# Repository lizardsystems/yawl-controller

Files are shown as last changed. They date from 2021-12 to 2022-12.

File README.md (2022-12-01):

# Yet Another WLED Controller

This repository contains a schematic and PCB layout for a yet another WLED controller (yawl-controller).

This is the ESP8266 based wireless pixel controller to drive addressable LED strips like WS2812B/APA102/WS2801/etc using WLED.



## Features



- Compact: 60x35x19mm with case, 59x32x12mm  without case.
- Supports 3-wire and 4-wire LED strips.
- Fuse for overcurrent protection.
- Reverse polarity protection.
- Modern [SN74LVC2T45](https://www.ti.com/product/SN74LVC2T45) bus transceiver with voltage translation. [Why?](level-shifter.md)
- Capacitor 1000 µF at 6.3V, smooths the voltage and sudden changes in demand for current from the LEDs.
- IR receiver (optional).
- Button (optional).
- Dallas temperature sensor for measuring ambient temperature inside of enclosure (optional).
- Connection to relay for reducing power consumption when seemingly switched off (optional).

## Some credits

Thanks to [Christian Schwinne aka Aircoookie](https://github.com/Aircoookie) who created an excelent [WLED Project](https://github.com/Aircoookie/WLED) - a fast and feature-rich implementation of an ESP8266/ESP32 webserver to control NeoPixel (WS2812B, WS2811, SK6812) LEDs or also SPI based chipsets like the WS2801 and APA102.

Schematics are based on manufacturers datasheets but some component values come from [Adafruit Learning System](https://learn.adafruit.com/) so thanks to Adafruit for keeping their products open source.

## The Idea

Small and simple device for 5V addressable LED strips with minimum components and fully assembled by PCB manufacturing service in standard case.

## Schematic

This is the schematic of YAWL controller

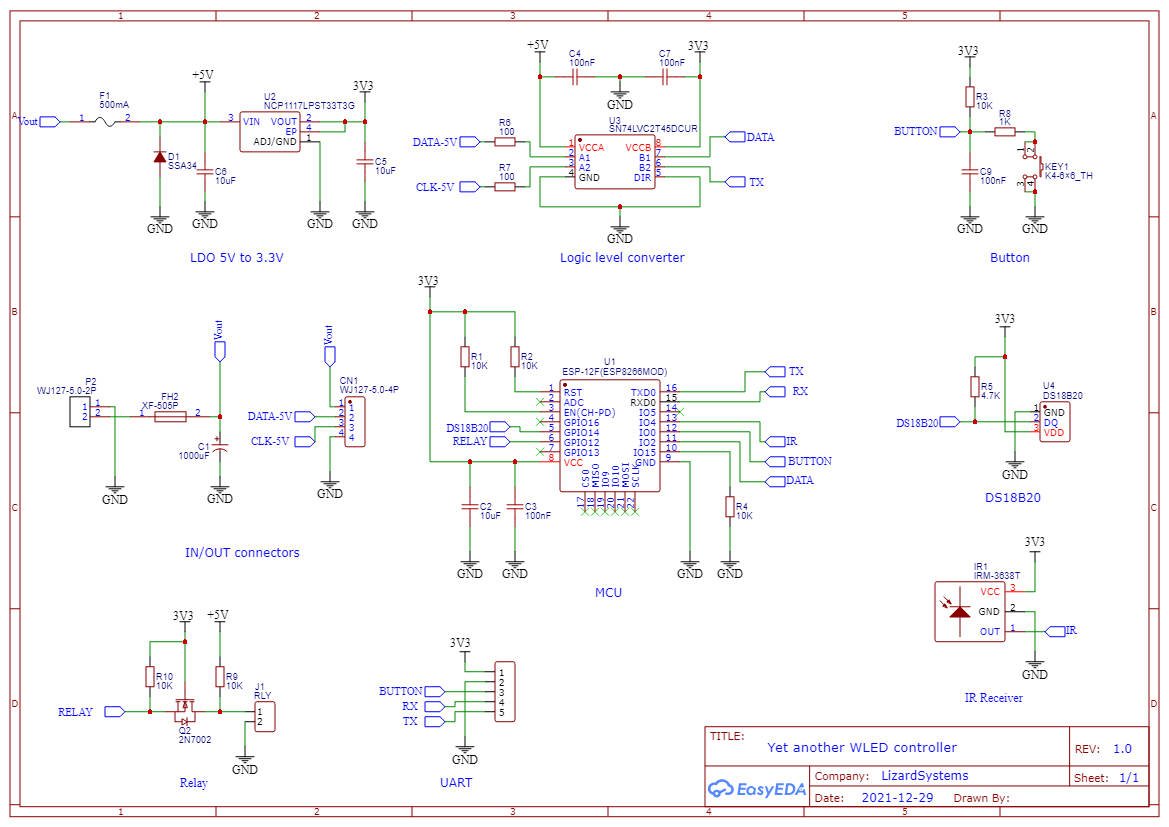
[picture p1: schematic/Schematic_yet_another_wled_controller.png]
Schematic


Download pdf file [Schematic_yet_another_wled_controller.pdf](Schematic_yet_another_wled_controller..pdf)

## GPIO Pinout

| Pin | Function |
| --- | ---|
| GPIO0 | Push Button |
|  GPIO1 | LED CLK |
|  GPIO2 | LED DATA |
|  GPIO4 | IR Receiver |
| GPIO12 | Relay |
| GPIO14 | Temperature Sensor |

## PCB

Dimensions:

- Width x Height: 59x32mm
- Thickness: 1.6mm

### 2D View

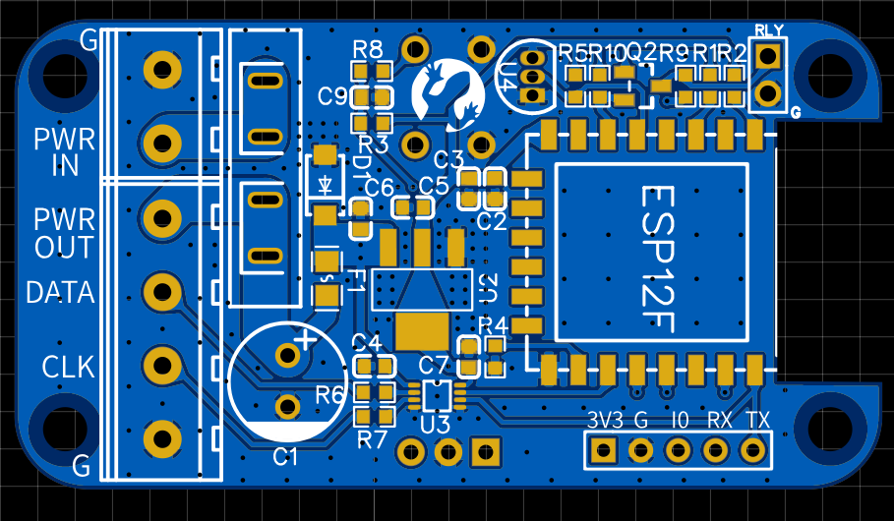
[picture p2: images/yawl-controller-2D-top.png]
2D View


### 3D View

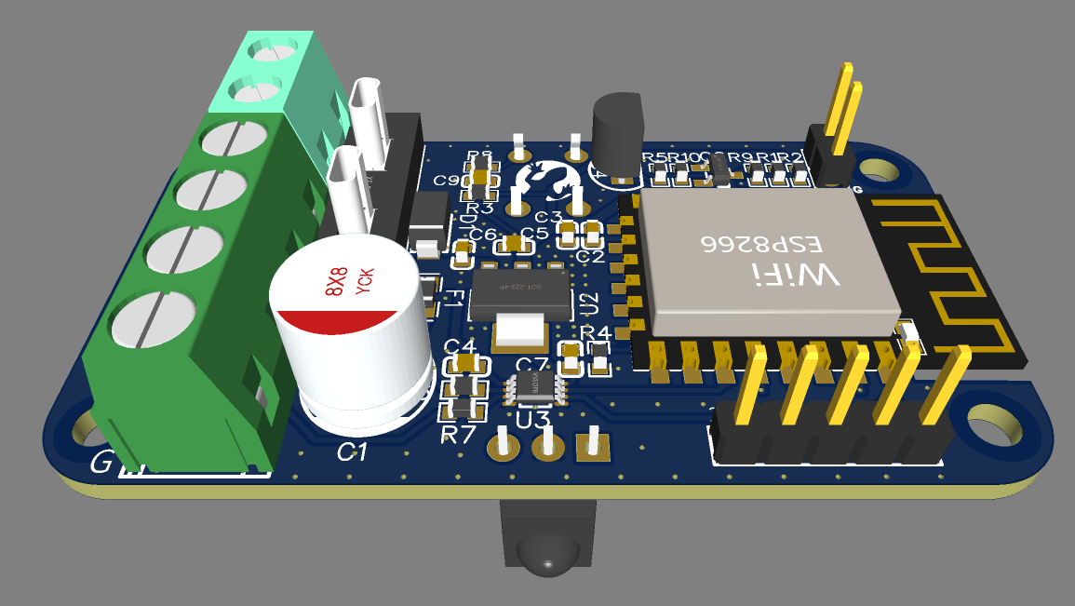
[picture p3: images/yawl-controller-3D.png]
3D View


## Enclosure

Read more about the YAWL controller [enclosures](/enclosures/README.md).

## Ordering and manufacturing

- Gerber files: [Gerber_PCB_yet_another_wled_controller.zip](fabrication/Gerber_PCB_yet_another_wled_controller.zip)
- BOM file: [BOM_PCB_yet_another_wled_controller.csv](fabrication/BOM_PCB_yet_another_wled_controller.csv)
- BOM file (JLCPCB): [BOM_PCB_yet_another_wled_controller_(JLCPCB).xls](fabrication/BOM_PCB_yet_another_wled_controller_(JLCPCB).xls)
- CPL file: [PickAndPlace_PCB_yet_another_wled_controller.csv](fabrication/PickAndPlace_PCB_yet_another_wled_controller.csv)

## Hardware

### PCB manufactured by JLCPCB



### SMT assembled PCB



### Manual soldering and assembling



- Fuse Holder [Micro](https://aliexpress.ru/item/4000541087990.html), Fuse 10A [Micro](https://aliexpress.ru/item/4000568246661.html) 
- IR Receiver (optional) [TSOP38238](https://aliexpress.ru/item/32834341300.html)
- Temperature Sensor (optional) [DS18B20](https://aliexpress.ru/item/32523899337.html)
- 3x Screw Terminal 5mm (optional) [2P](https://aliexpress.ru/item/4000084631795.html)
- Relay Screw Terminal 2.54mm (optional) [2P](https://aliexpress.ru/item/4000867583795.html)
- Push Button (optional) [6x6x9mm](https://aliexpress.ru/item/32912104842.html)
- DC Power Pigtail Female Plug [5.5x2.1mm](https://www.aliexpress.com/af/pigtail-dc-female-5.5x2.1mm.html)
- JST SM Connector [3pin](https://www.aliexpress.com/item/1718558728.html)
- Enclosure (optional) [80x38x22mm-Black](https://aliexpress.ru/item/1005002656761229.html) or [style 2](https://aliexpress.ru/item/1005001677364663.html)

### Assembled device



With all optional parts



### With enclosure



## Ready to use firmware

- [Custom WLED Firmware](firmware/WLED/)
- [Custom ESPHome Firmware](firmware/ESPHome)

## Resources

- [WLED](https://github.com/Aircoookie/WLED) 
- [ESPHOME](https://esphome.io/)

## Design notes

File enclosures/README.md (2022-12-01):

# Enclosures

## Ready-to-use enclosures

PCB is designed for SZOMK [AK-S-80](/datasheets/AK-S-80.pdf) case

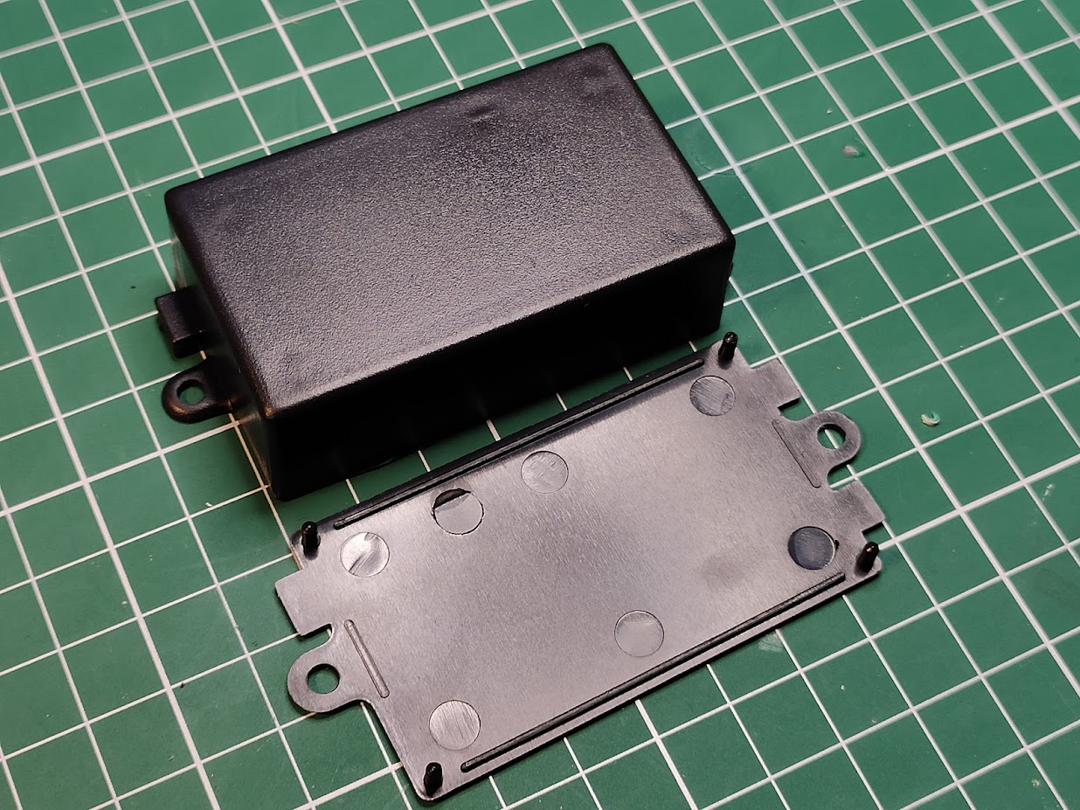
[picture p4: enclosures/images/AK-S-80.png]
AK-S-80


Buy on Aliexpress: [80x38x22mm-Black](https://aliexpress.ru/item/1005002656761229.html) or [style 2](https://aliexpress.ru/item/1005001677364663.html)

## 3D printed enclosures

Two enclosures designed by [@chunkysteveo](https://github.com/chunkysteveo) based on [Customizable everything box (waterproof) by mcseven](https://www.thingiverse.com/thing:1680291/files)

The screw holes are 3.4mm diameter, that allows to get an M3 screw through the lid, and melt an M3 threaded insert into the body.

### With external antenna

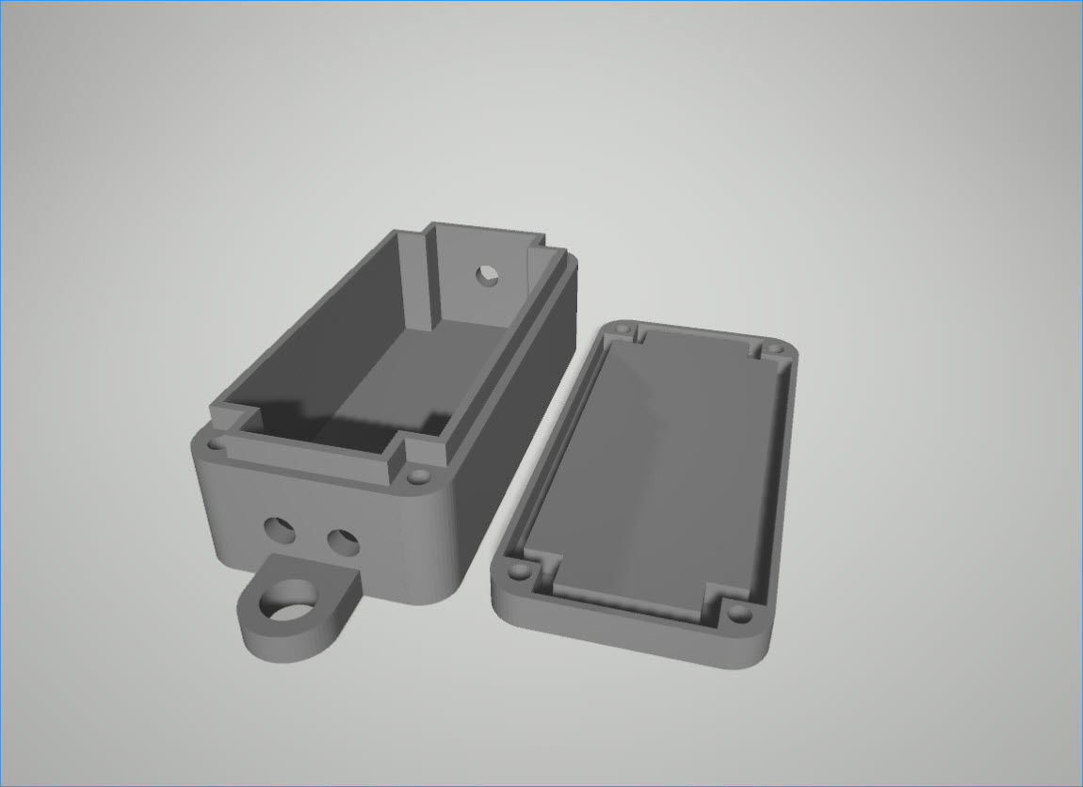
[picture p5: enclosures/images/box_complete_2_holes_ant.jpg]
box_complete_2_holes_ant


Download STL file: [box_complete_2_holes_ant.zip](/enclosures/box_complete_2_holes_ant.zip)

### Without external antenna  

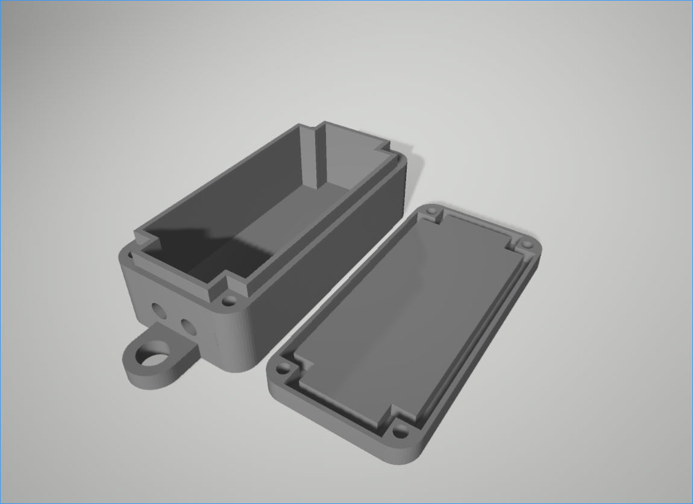
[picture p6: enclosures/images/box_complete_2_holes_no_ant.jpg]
box_complete_2_holes_no_ant


Download STL file: [box_complete_2_holes_no_ant.zip](/enclosures/box_complete_2_holes_no_ant.zip)

### YAWL controller in 3D printed enclosure

3d-printed-enclosure

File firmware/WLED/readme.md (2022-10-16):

wled_logo_akemi

# WLED

## Download ready-to-use firmware

### YAWL firmware
You may download a ready-to-use firmware [yawl_controller.bin ](firmware/WLED/bin/yawl_controller.bin).

### Standard firmware

You can get further information on the various WLED firmware versions https://kno.wled.ge/basics/install-binary/

## Build custom firmware

Also you may compile the firmware by self using Visual Studio Code and Platformio. 
 - Download and install Git client: https://git-scm.com/downloads.
 - Download and install Visual Studio Code: https://code.visualstudio.com/download.
 - Install PlatformIO extension in Visual Studio Code: https://docs.platformio.org/en/latest//integration/ide/vscode.html#installation
 - Download WLED Github Master ZIP: https://github.com/Aircoookie/WLED/archive/refs/heads/master.zip
 - Unpack in directory somewhere
 - "Open folder" in Visual Studio Code
 - Build project with <kbd>Ctrl</kbd>+<kbd>Alt</kbd>+<kbd>B</kbd> hotkey
 - Build standard WLED.
 - If the file is created successfully then you can proceed to the next step, if not please read [this article](https://kno.wled.ge/basics/compiling-wled/) for more information.  
 - Copy [platformio_override.ini](platformio_override.ini) to WLED folder 
 - Build custom WLED firmware.
 - Please find built firmwae in WLED/build_output/firmware folder



If you still have questions for more information please read a step-by-step guide at [this page](https://kno.wled.ge/basics/compiling-wled/) of the WLED Wiki    

## Build the firmware from command line

 - Edit file **env.cmd** from yawl-controller/firmware/ESPHome/ directory. 
   - Set `PYTHON_PATH` to Python installed on your system.
   - Set `PLATFORMIO_VENV` to path to virtual environment where Platformio will be installed.
   - Set `PLATFORMIO_REPO` to url for Platformio repository. Default: https://github.com/platformio/platformio-core
   - Set `PLATFORMIO_BRANCH` to branch name or tag in Platformio repository. Default: master
   - Set `WLED_REPO` to url for WLED repository. Default: https://github.com/Aircoookie/WLED
   - Set `WLED_BRANCH` to branch name or tag in WLED repository. Default: master
 - Run **install_platformio.cmd**. The latest version of Platformio will be installed.
 - Run **compile.cmd**. The firmware will be compiled and copied to yawl-controller/firmware/WLED/ directory. File **yawl_controller_WLED_`{WLED_VERSION}`.bin** will be created, where `{WLED_VERSION}` - version of WLED.  

## Connect controller to computer

| YAWL Controller |	USB to Serial Adapter|
|---|---|
| 3.3v	| 3.3v |
| Ground	| Ground |
| IO0	| Ground |
| TX	| RX |
| RX	| TX |



## Flash firmware
Download flasher https://github.com/esphome/esphome-flasher/releases
Open the flasher tool.
 - Serial port: select COM port where the controller is connected (there is probably only one option).
 - Firmware: Browse to the location where you downloaded your compiled firmware and select your firmware.



- Click Flash ESP and wait.

The controller will be flashed now, you can follow the progress in the console window.
When finished writing the firmware, switch off controller.

## Hardware Setup

### GPIO Pinout
| Pin | Function | 
| --- | ---|
| GPIO0 | Push Button | 
|  GPIO1 | LED CLK |
|  GPIO2 | LED DATA |
|  GPIO4 | IR Receiver |
| GPIO12 | Relay | 
| GPIO14 | Temperature Sensor |

### 3-Wire LED Strip 


1. Select 3-wire LED Strip like a WS281x
2. Data GPIO: 2 

### 4-Wire LED Strip


1. Select 4-wire LED Strip like a APA102
2. GPIOs: 
   - Data GPIO: 2
   - Clk GPIO: 1

### Temperature


YAWL Controller uses GPIO 14 for temperature sensor DS18B20 (DALLAS)



### IR receiver


YAWL controller uses GPIO 4 for IR receiver. 

Information about infrared receivers https://kno.wled.ge/interfaces/infrared/

### Relay


YAWL controller uses GPIO 12 for controlling relay. 

Installing relay https://kno.wled.ge/features/relay-control/

### Button


YAWL controller uses GPIO 0 for button. 

## Multi-strip Support

You are able to use multiple LED outputs from one yawl-controller. Pins and LED numbers can be easily configured in LED settings, you don't need to re-compile code for your specific setup. You may use use two specific LED pins, GPIO1 (CLK) and GPIO2 (DATA) for two 3-wires strips 

### GPIO Pinout
| Pin | Function | 
| --- | ---|
|  GPIO1 | LED DATA #1 |
|  GPIO2 | LED DATA #2 |

### Wiring



### WLED Config



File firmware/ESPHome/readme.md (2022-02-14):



# ESPHome

## FastLED or NeoPixelBus
You may create your own firmaware using ESPHome and FastLED or NeoPixelBus library or download ready to use firmware.

For more information about FastLED library:
- ESPHome FastLED Light Platform https://esphome.io/components/light/fastled.html
- FastLED repository https://github.com/FastLED/FastLED
- ESPHome NeoPixelBus Light Platform https://esphome.io/components/light/neopixelbus.html
- NeoPixelBus repository https://github.com/Makuna/NeoPixelBus

### Download ready to use firmware

Download firmware [yawl-controller-fastled.bin](yawl-controller-fastled.bin) or  [yawl-controller-neopixelbus.bin](yawl-controller-neopixelbus.bin) from this repository for 3-wire LED strip (NeoPixels, one data wire). If you want to use 4-wire LED strip (DotStars, two wire, one data and one clock) please read below. 

### Build the firmware itself

#### 3-Wire LED Strip

NeoPixels, one data wire:
- WS2811, WS2812, WS2812b, WS2813
- APA106
- SK6812
- LC8812
- TM1814,TM1914,TM1829

Download YAML configuration file [yawl-controller-neopixelbus.yaml](yawl-controller-neopixelbus.yaml) or [yawl-controller-fastled.yaml](yawl-controller-fastled.yaml) from this repository and compile using ESPHome.

#### 4-Wire LED Strip

DotStars, two wire, one data and one clock
- APA102
- SK9822
- LPD6803, LPD8806
- WS2801
- P9813

##### FastLED

Please change light options in yawl-controller-fastled.yaml

```yml
light:
  - platform: fastled_spi
    id: light_1
    rgb_order: GRB
    chipset: APA102
    data_pin: GPIO2
    clock_pin: GPIO1
```
#### NeoPixelBus

**Unfortunately NeoPixelBus does not support GPIO2 and GPIO1 for 4-wire LED strip. On ESP8266 NeoPixelBus supports only GPIO13 for data_pin and only GPIO14 for clock_pin.** 

Please read [Getting Started with ESPHome](https://esphome.io/guides/getting_started_command_line.html) and [Getting Started with ESPHome and Home Assistant](https://esphome.io/guides/getting_started_hassio.html)

### Build the firmware from command line

If you want to flash firmware from command line you may skip this section and go to "**Flash using command line**"

 1) Edit file **env.cmd** from yawl-controller/firmware/ESPHome/ directory. 
   - Set `PYTHON_PATH` to Python installed on your system.
   - Set `ESPHOME_VENV` to path to virtual environment where ESPHome will be installed.
   - Set `ESPHOME_REPO` to url for ESPHome repository. Default: https://github.com/esphome/esphome
   - Set `ESPHOME_BRANCH` to branch name or tag in ESPHome repository. Default: release
 2) Run **install_esphome.cmd**. The latest version of ESPHome will be installed.
 3) Run **compile_fastled.cmd** or **compile_neopixelbus.cmd**. The firmware will be compiled and copied to yawl-controller/firmware/ESPHome/ directory. yawl-controller-fastled.bin or yawl-controller-neopixelbus.bin will be updated.  

## Connect controller to computer

| YAWL Controller |	USB to Serial Adapter|
|---|---|
| 3.3v	| 3.3v |
| Ground	| Ground |
| IO0	| Ground |
| TX	| RX |
| RX	| TX |



## Flash firmware

### Flash using ESPHome Flasher

- Download flasher https://github.com/esphome/esphome-flasher/releases
 - Open the flasher tool.
   - Serial port: select COM port where the controller is connected (there is probably only one option).
   - Firmware: Browse to the location where you downloaded your compiled firmware and select your firmware.
   - Click Flash ESP and wait.

esphome_flash

The controller will be flashed now, you can follow the progress in the console window.
When finished writing the firmware, switch off controller.

### Flash using command line

1) Edit file **env.cmd** from yawl-controller/firmware/ESPHome/ directory. 
   - Set `PYTHON_PATH` to Python installed on your system.
   - Set `ESPHOME_VENV` to path to virtual environment where ESPHome will be installed.
   - Set `ESPHOME_REPO` to url for ESPHome repository. Default: https://github.com/esphome/esphome
   - Set `ESPHOME_BRANCH` to branch name or tag in ESPHome repository. Default: release
2) Run **install_esphome.cmd**. The latest version of ESPHome will be installed.

Once done, you can then go ahead and run the following command **flash_fastled.cmd** or **flash_neopixelbus.cmd** which will instruct ESPHome to flash YAWL controller firmware. This will take a minute or two to complete, at which point you will then be asked how you want to upload. Select the option for serial and it should begin to upload.

yawl_flash

Assuming everything was successful, you can now disconnect everything from the USB adaptor.

## Connect controller to Wi-Fi network

When you are using ready-to-use firmware, at the first start, the controller will create its own network "yawl-controller-XXXXXX". 

When you are connecting to the fallback network, the web interface should open automatically (see also login to network notifications). If it doesn't open, you may also navigate to http://192.168.4.1/ manually in your browser.



In this web interface, you may manually override the WiFi settings.

Additionally, you may upload a new firmware file.

## See also
 - https://esphome.io/guides/getting_started_hassio.html

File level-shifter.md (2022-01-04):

# Level shifter

yawl-controller uses SN74LVC2T45 as level shifter - 2-Bit Dual Supply Transceiver with Configurable Voltage-Level Shifting and 3-State Outputs. 

[SN74LVC2T45 Datasheet](datasheets/1809042112_Texas-Instruments-SN74LVC2T45DCUR_C15741.pdf)

## Speed

SN74LVC2T45 2x faster than SN74AHCT125N and 4x faster than SN74HCT125N



## Size

SN74LVC2T45 8x smaller than SN74AHCT125N

- SN74AHCT125N (PDIP-14) 19.05x6.35x3.3mm 
- SN74LVC2T45DCUR  (VSSOP-8) - 2x2.3x1mm



## Price

 - SN74AHCT125N - [US$ 0.29](https://lcsc.com/product-detail/Buffers-Drivers_Texas-Instruments-SN74AHCT125N_C354152.html)
 - SN74LVC2T45DCUR - [US$ 0.44](https://lcsc.com/product-detail/Receivers-Transceivers_Texas-Instruments-SN74LVC2T45DCUR_C15741.html)

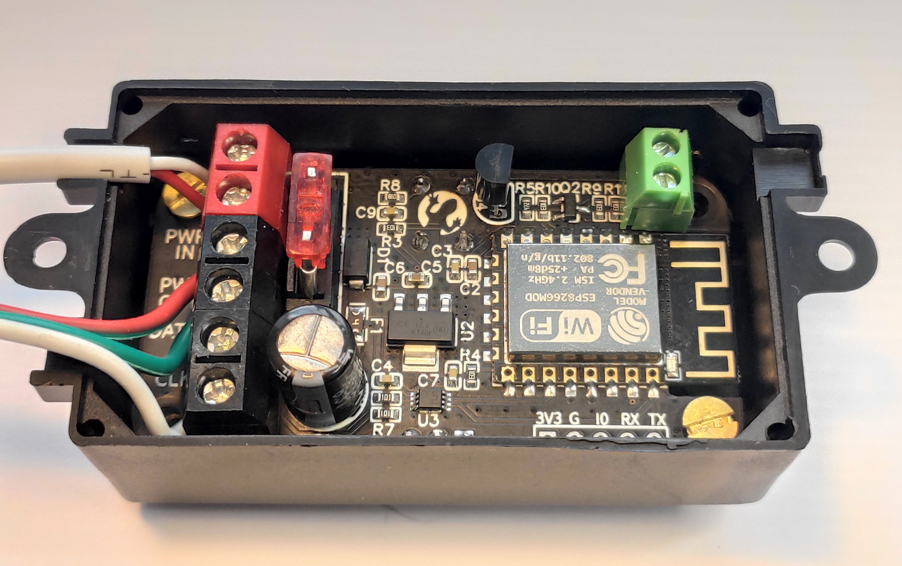
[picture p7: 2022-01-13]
images/yawl-controller-with-case.jpg

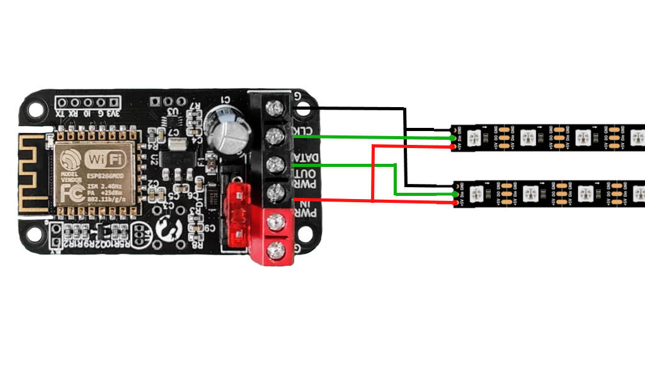
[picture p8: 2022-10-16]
images/yawl-controller-multi-strip-support.jpg

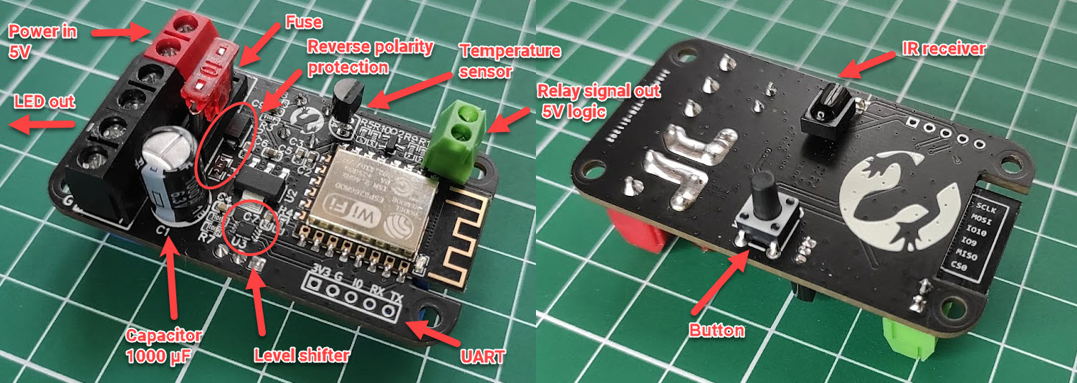
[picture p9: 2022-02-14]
images/yawl-controller-features.jpg

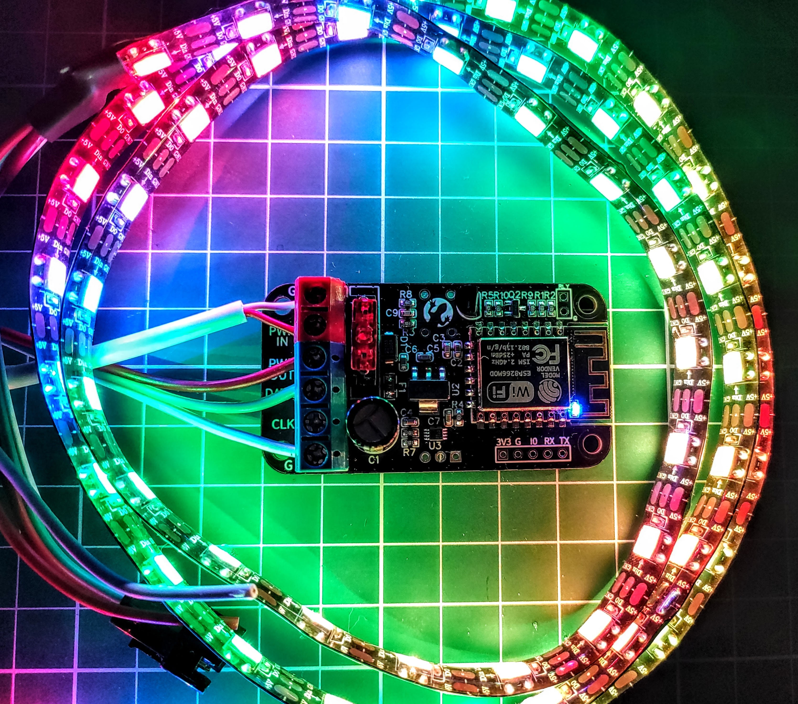
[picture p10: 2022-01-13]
images/yawl-controller.jpg

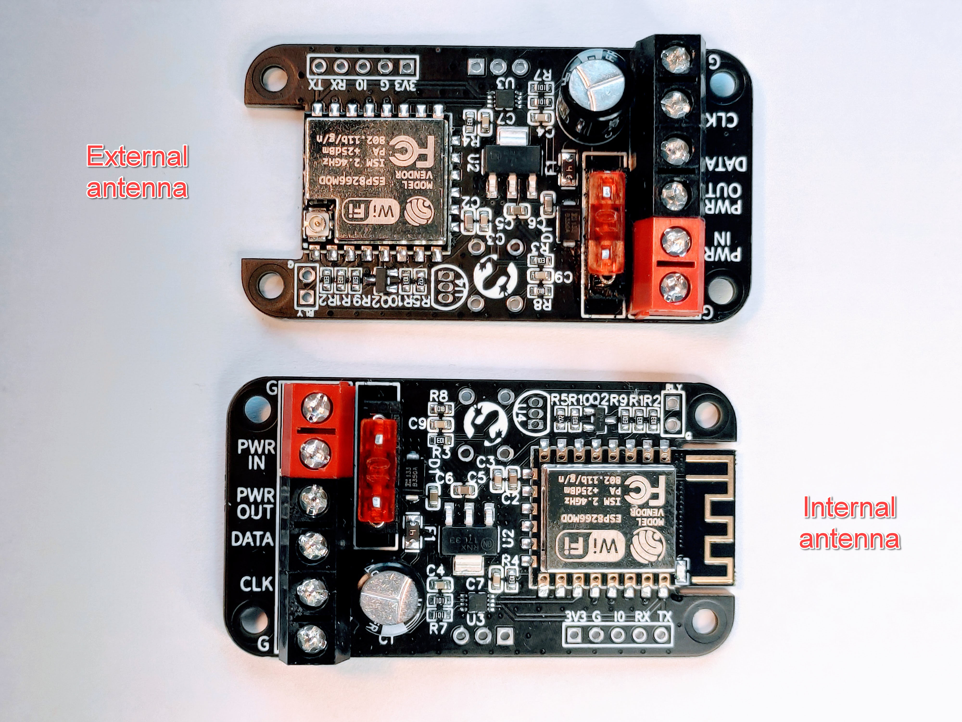
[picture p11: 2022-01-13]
images/yawl-controller-antenna-variations.jpg

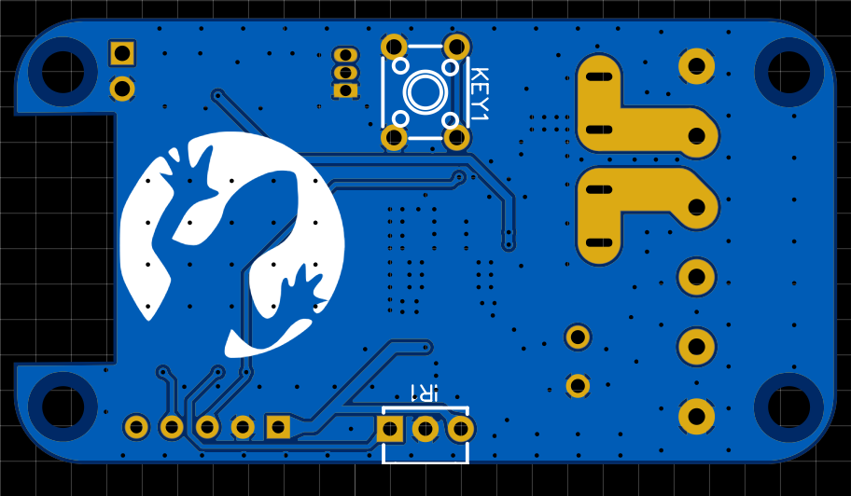
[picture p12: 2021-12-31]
images/yawl-controller-2D-bottom.png

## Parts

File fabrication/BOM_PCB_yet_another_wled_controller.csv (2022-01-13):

ID | Name | Designator | Footprint | Quantity | Manufacturer Part | Manufacturer | Supplier | Supplier Part | Price
1 | 1000uF | C1 | CAP-TH_BD8.0-P3.50-D0.6-FD | 1 | 1000uF 10V 8*12 | ValuePro | LCSC | C10752 | 0.03
2 | 10uF | C2,C5,C6 | C0603 | 3 | CL10A106KP8NNNC | SAMSUNG | LCSC | C19702 | 0.006
3 | 100nF | C3,C4,C7,C9 | C0603 | 4 | CC0603KRX7R9BB104 | YAGEO | LCSC | C14663 | 0.002
4 | WJ127-5.0-4P | CN1 | CONN-TH_4P-P5.00_WJ127-5.0-4P | 1 | WJ127-5.0-4P | Ningbo Kangnex Elec | LCSC | C192779 | 0.193
5 | SS34 | D1 | DO-214AC_L4.3-W2.7-LS5.3-RD | 1 | SS34 | MDD | LCSC | C8678 | 0.04
6 | 500mA | F1 | F0805 | 1 | MF-PSMF050X-2 | BOURNS | LCSC | C116170 | 0.025
7 | XF-505P | FH2 | FUSE-TH_XF-505P | 1 | XF-505P | XFCN | LCSC | C843270 | 0.15
8 | IRM-3638T | IR1 | OPTO-TH_IRM-3638T | 1 | IRM-3638T | EVERLIGHT | LCSC | C16216 | 0.217
9 | K4-6×6_TH | KEY1 | KEY-TH_4P-L6.0-W6.0-P4.50-LS6.5 | 1 | K2-1102DP-E4SW-04 | 韩国韩荣 | LCSC | C136684 | 0.036
10 | WJ127-5.0-2P | P2 | CONN-TH_2P-P5.00_CPC3703CTR | 1 | WJ127-5.0-2P | ReliaPro | LCSC | C3703 | 0.119
11 | 2N7002 | Q2 | SOT-23-3_L2.9-W1.3-P1.90-LS2.4-BR | 1 | 2N7002 | CJ | LCSC | C8545 | 0.021
12 | 10K | R1,R2,R3,R4,R9,R10 | R0603 | 6 | 0603WAF1002T5E | UniOhm | LCSC | C25804 | 0.001
13 | 4.7K | R5 | R0603 | 1 | 0603WAF4701T5E | UniOhm | LCSC | C23162 | 0.001
14 | 100 | R6,R7 | R0603 | 2 | 0603WAF1000T5E | UniOhm | LCSC | C22775 | 0.001
15 | 1K | R8 | R0603 | 1 | 0603WAF1001T5E | UniOhm | LCSC | C21190 | 0.001
16 | ESP-12F(ESP8266MOD) | U1 | WIFIM-SMD_ESP-12F-ESP8266MOD | 1 | ESP-12F(ESP8266MOD) | Ai-Thinker | LCSC | C82891 | 1.48
17 | NCP1117LPST33T3G | U2 | SOT-223_L6.5-W3.5-P2.30-LS7.0-BR | 1 | NCP1117LPST33T3G | ON | LCSC | C146799 | 0.273
18 | SN74LVC2T45DCUR | U3 | VSSOP-8_L2.4-W2.1-P0.50-LS3.2-BR | 1 | SN74LVC2T45DCUR | TI | LCSC | C15741 | 0.387
19 | DS18B20 | U4 | TO-92-3_L4.9-W3.7-P1.27-L | 1 | DS18B20 | Youtai Semiconductor Co., Ltd. | LCSC | C376006 | 0.798

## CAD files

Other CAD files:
datasheets/AK-S-80.dxf
datasheets/AK-S-80.dwg

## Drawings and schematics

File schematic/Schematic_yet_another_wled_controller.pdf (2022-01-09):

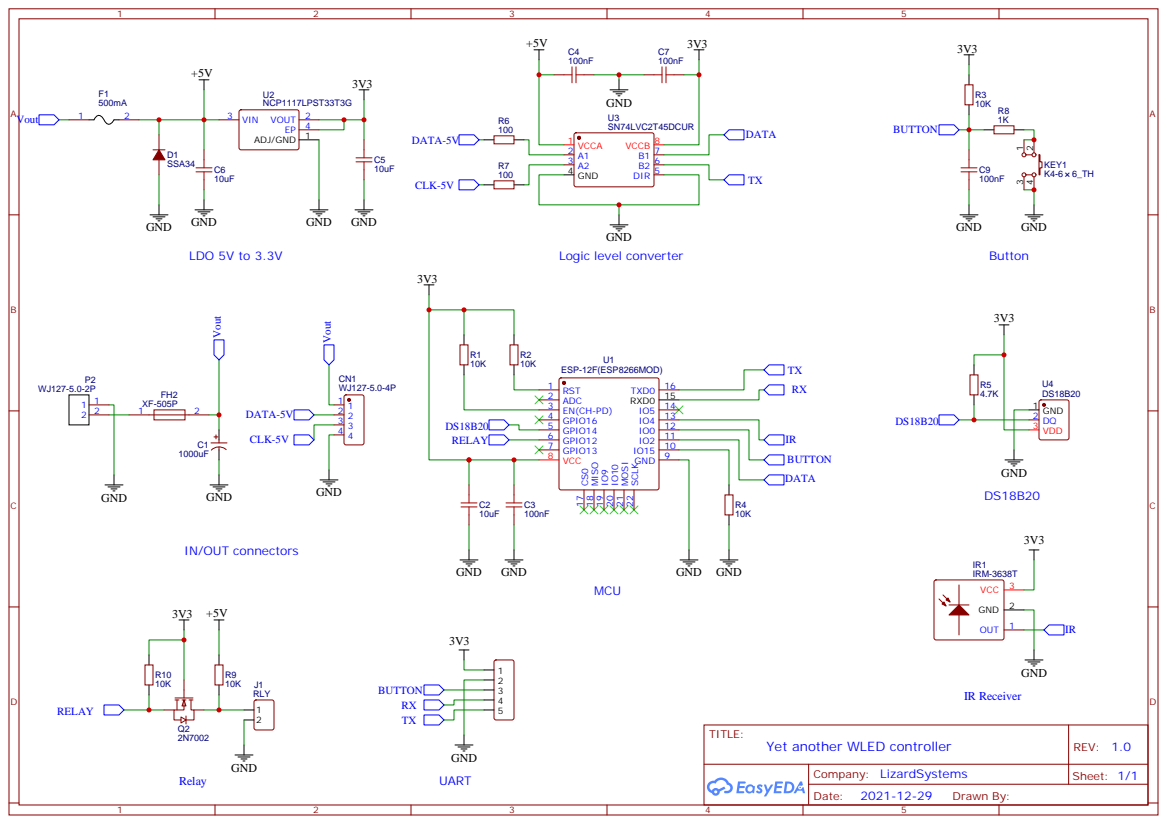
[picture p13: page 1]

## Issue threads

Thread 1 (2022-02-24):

YAWL - Order @ JLCPCB - CPL-File

Masterbandit, 2022-02-24:
Hi,

I am interested in your controller and tried to order it at JLCPCB to create and assemble the pcb.
It is all working fine until the last step. When I add BOM and CPL and press Enter, it takes a long
time and it appears the error "Incorrect format" "Failed processing the CPL file". I tried both BOMs
with the one CPL.

Can you please check this, I really want to try your nice controller.

Sincerely

Masterbandit

vzagorovskiy, 2022-02-24:
Hi,
Do not download file from link

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

 Please download zip file from main page https://github.com/lizardsystems/yawl-controller/

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

Closed 2022-03-03.

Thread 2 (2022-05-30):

maximum Current

moonilightshaker, 2022-05-30:
Hello, what are the maximum current for the Power traces?
Thanks

vzagorovskiy, 2022-05-30:
All Christmas and New Year holidays the controller worked successfully with 200 LEDs on the Christmas tree. The temperature of the board did not exceed 35 degrees Celsius. By all calculations, if you strengthen the tracks as shown in the photo, the controller should work up to 8A-10A. If you need more, it is better to connect as shown in the diagram below.

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

moonilightshaker, 2022-05-30:
Thanks for the Info.

Closed 2022-05-31.

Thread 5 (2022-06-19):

Can this board also work with 12v?

mctigger, 2022-06-19:
Hi,
I am wondering whether this board will work with 12v or needs some small modifications?

vzagorovskiy, 2022-06-20:
You may use use a separate power supply or a dc-dc converter
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

mctigger, 2022-06-20:
Thank you, so an additional buck-converter is needed.

Closed 2022-06-20.

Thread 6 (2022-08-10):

Fuze F1 necessary?

PhillipRt, 2022-08-10:
Is the Fuze F1 (MF-PSMF050X-2) a required part or can I bridge it with solder? The part is out of stock everywhere.

vzagorovskiy, 2022-08-10:
Hello, you may use C20978 or any 6V 500mA  0805 Resettable Fuses

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

vzagorovskiy, 2022-08-10:
It is part of reverse polarity protection circuit. Yes,  you may not use this element, but it may not be safe if you accidentally reverse the power polarity.

chunkysteveo, 2022-09-13:
https://lcsc.com/product-detail/Resettable-Fuses_BOURNS-MF-PSMF050X-2_C116170.html

180 in stock currently at time of posting this @PhillipRt

Closed 2022-11-25.

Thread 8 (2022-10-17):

Ordering instructions for JLCPCB

habeas81, 2022-10-17:
I've never ordered a PCB, though I've considered it many times.  I'd appreciate it greatly if this repo had an ordering guide for what options to choose in terms of the PCB production and assembly.  I'm happy to create it and commit it if you might be willing to help me walk through what I should choose on the website.

Thanks in advance!  Awesome work and super grateful for you creating and sharing this.

vzagorovskiy, 2022-10-17:
https://oshwlab.com/Daisy/How-To-Order-SMT-Service-From-JLCPCB-PCB-Components

Closed 2022-11-25.

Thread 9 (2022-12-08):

Version with swappable esp8266/32

Dunky13, 2022-12-08:
Have a pcb versions with headers I stead of the soldered esp12f.
Either a D1 edition, or a "full size" nodemcu version?

So the pcb is bare board, and a controller can be plugged in.

Useful for people who don't have, or don't want to use an ftdi programming board, or worry about connecting ground to g(nd) and io.

vzagorovskiy, 2022-12-08:
You may use [quinled controllers](https://quinled.info/pre-assembled-quinled-dig-uno/) or shields from serg74[tindie](https://www.tindie.com/products/serg74/wled-mini-shield-board-for-addressable-leds/)

chunkysteveo, 2023-04-26:
Something I'm working on @Dunky13  [TTGO T-Micro32 board](https://github.com/lizardsystems/yawl-controller/issues/13)

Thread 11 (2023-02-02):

Board Source?

aaron-harvey, 2023-02-02:
Hello, I'd like to add esp32 support, is it possible to get the source file to make modifications?

chunkysteveo, 2023-04-26:
Something I'm working on @aaron-harvey [TTGO T-Micro32 board](https://github.com/lizardsystems/yawl-controller/issues/13)

vzagorovskiy, 2023-04-26:
[yawl-controller.zip](https://github.com/lizardsystems/yawl-controller/files/11333740/yawl-controller.zip)

EasyEDA files

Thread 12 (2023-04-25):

Possibility of breaking out the ADC for an electret Mic. Reactive lights

TheBestJohn, 2023-04-25:
Looks as if Pin 2 is unused, If it was broken out to a header then we could use it to enable reactive lights with a mic.
Maybe break out all unused pins and add a ground and 3.3v pin for good measure to allow for modifications?

TheBestJohn, 2023-04-25:
Alternative if anyone really wants this is sending UDP frames, it does cut out the WLED side though, you're essentially just turning it into a network RGB strip instead of leaning on the processing. That being said, the ESP8266 processing limitations may just make this not worth the effort for this project.

Closed 2023-04-25.

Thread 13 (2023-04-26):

New adapter for ESP32 (TTGO T-Micro32)

chunkysteveo, 2023-04-26:
I'm just in the middle of an experiment to piggyback a TTGO T-micro32 board onto the YAWL board... uses an adapter PCB which maps the pins from the ESP12-F footprint to the ESP32.... not tested, but will be happy to opensource if it doesn't blow up on first switch on!!!
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

You'll need hotair or a hotplate for this to work.....
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

numindast, 2023-04-26:
that is definitely clever!

chunkysteveo, 2023-04-26:
> that is definitely clever!

Tell me again if I get it working!! Haha

nocodeman55, 2023-05-18:
What about using the AI Thinker ESP32-C3 12F module?
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

chunkysteveo, 2023-05-18:
I had thought of that board - but the C3 support in WLED is terrible at best. Was looking for maximum plug and play compatibility with a stock EDP32.

nocodeman55, 2023-05-18:
Where did you find that TTgo adapter/card?

vzagorovskiy, 2023-05-19:
The board is slightly changed in the new version, which will allow the use of esp32-c3. After receiving the boards and checking them, I will publish the source files on the github.

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

chunkysteveo, 2023-05-19:
> Where did you find that TTgo adapter/card?

Haha - I found it in my head and made the PCB in KiCad, lol! I've done an initial test but it didn't upload any firmware... I may need to tweak the PCB, but when/if it gets working - I'll open source it, so you could send the gerbers to get a PCB made.

chunkysteveo, 2023-05-19:
> The board is slightly changed in the new version, which will allow the use of esp32-c3. After receiving the boards and checking them, I will publish the source files on the github.
>
> 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

That's a cool design - does WLED work well with the C3 now?

chunkysteveo, 2023-05-19:
> The board is slightly changed in the new version, which will allow the use of esp32-c3. After receiving the boards and checking them, I will publish the source files on the github.
>
> 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

My favourite feature on that board is the 5V pin with the relay connection! 👍🏻

vzagorovskiy, 2023-05-19:
> That's a cool design - does WLED work well with the C3 now?
I will test it.  🤞

chunkysteveo, 2023-05-19:
Pic or it never happened! Lol

Would love to use some of your C3 boards if you can show it working well! My little TTGO adapter board is handy, but those T-Micro32 boards are $6-7 each! C3 is way more friendly on the pocket!!

Keep us posted!!

chunkysteveo, 2023-06-12:
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
This may look like a mess - but my adapter board can be programmed and is currently running ESPHome and all sensors and features are functioning:

Not tested WLED yet - need to learn how to compile a custom binary!

nocodeman55, 2023-06-12:
I would love to try your adapter, this is really cool!

chunkysteveo, 2023-06-12:
Testing in WLED - I cannot get a binary to upload without either a boot loop or just dead board. There is an issue with the T-Micro32 and WLED by the looks of it. ..?! EsPHome works fine, WLED not so. I think I need to check the environments for similarities??

chunkysteveo, 2023-06-13:
Success! I now have the TTGO T-Micro32 running WLED on the YAWL board with my adapter board. All original aspects and features of the YAWL board have been replicated and work great (IR, Relay, 2 output or 1 data/clock, Temp sensor, button).

I'll get the gerbers for the board online ASAP, and some links to the TMicro32 boards on Ali.

chunkysteveo, 2023-06-14:
> Success! I now have the TTGO T-Micro32 running WLED on the YAWL board with my adapter board. All original aspects and features of the YAWL board have been replicated and work great (IR, Relay, 2 output or 1 data/clock, Temp sensor, button).
>
> I'll get the gerbers for the board online ASAP, and some links to the TMicro32 boards on Ali.

I may amend the PCB - add a ground pad for under the TMicro 32 module, just for heat dissipation to suck some heat away to the bottom - this thing is hot!

DieKatzchen, 2023-08-03:
> The board is slightly changed in the new version, which will allow the use of esp32-c3. After receiving the boards and checking them, I will publish the source files on the github.
>
> 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

Any updates?

chunkysteveo, 2023-08-03:
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

My ground pad ones came in for the TTGO boards, and work well. I'll get my files up online!

chunkysteveo, 2023-09-26:
I'm having an issue with the power up of the board via the 5V source and capacitor C9 on the GPIO0 pin. Looks like it's not coming up high quick enough on power up - only a bridge from GPIO0 to 3V3 will get the board to boot.

My guess is that C9 it taking too long to charge up and causing the pin not to be HIGH quick enough on boot? Once booted the pin works perfectly fine as the button pin. I'm going to try with a smaller value capacitor (less than 100nF) to see if that helps with a more consistent power up behaviour - but would be curious if people think this is the wrong idea?!

Dunky13, 2024-01-06:
Any updates on this?

chunkysteveo, 2024-02-07:
> Any updates on this?

Hey @Dunky13  - yes, kind of completed, but I wouldn't recommend it as a route. It would be better to design the board around a cheaper ESp32 WROOM chip, and take advantage of the extra pins for more data line outs, fix some niggles on the board, add a mic if needed etc etc.

However, if you want to use a TTGO T-Micro32, the gerbers for JLCPCB or OshPark are below:

[ttgo-t-micro32-to-esp12f.zip](https://github.com/lizardsystems/yawl-controller/files/14202477/ttgo-t-micro32-to-esp12f.zip)

The carrier board works, but I needed to manually pull GIIO0 to ground using a jump wire to get it into Flash mode. And after that - it turns out the capacitor on the GPIO0 button wasn't pulling it back up quick enough on boot, so I had to remove C9 (once removed it would reboot without any issues).

Once built, I created a custom build of WLED with the new pins for the ESP32 for the two data lines, relay, IR, button and temp sensor. They all worked perfect once built and I have had two running over Christmas - one running a 1000 LED MegaTree for two months, and it never failed me once!

If you want to build this, you will need a hotplate or hot air gun, as the pads have no room to be castillated, so they rely on solder flowing. I will have to dig out my Platform IO config that shows which pins are what, and what environment to use... that's on a different computer. But feel free to download the gerbers and then the boards made.

I'd recommend a mini heat sink to stick on the can too - the TTGO runs hot, hence why I re-designed my board to have a ground pad and lots of vias to try to act as a heat spreader.

I'd be more inclined to go with @vzagorovskiy design if it's finished?

Oh, and a final tip - one of mine I lost the main data line (somehow???!), but as it's an ESP32, you can use almost any pin as a data line, so I used the relay pin for one string - the transistor that flips the relay 5V line is fast enough to cope with the data packets, so technically if you go with this, and you omit the relay use - you can have 3x data lines out of this little board!

chunkysteveo, 2024-02-07:
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

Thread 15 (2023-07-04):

update bin

iamlite, 2023-07-04:
Hey! Any chance for a firmware update for b3?

numindast, 2023-07-04:
You can find the official binaries at the [Aircookie/WLED](https://github.com/Aircoookie/WLED/releases) github. You'd use the [WLED_0.14.0-b3_ESP8266.bin] firmware. You can also use https://install.wled.me/ which has a web-based tool to flash the firmware too. Note that this firmware does NOT include the Dallas temperature sensor usermod though.

vzagorovskiy, 2023-07-05:
> Hey! Any chance for a firmware update for b3?

Done! https://github.com/lizardsystems/yawl-controller/tree/main/firmware/WLED

iamlite, 2023-07-12:
Thank you!

Closed 2023-11-20.

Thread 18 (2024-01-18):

Yet Another Firmware Update Request

iamlite, 2024-01-18:
Hello! Here again to bug you for a firmware update.

chunkysteveo, 2024-12-09:
[wled_14.4_YAWL.zip](https://github.com/user-attachments/files/18063786/wled_14.4_YAWL.zip)

Try this - it's been built using the online compiler - https://wled-compile.github.io/ but works well for me. If you're updating from v14.0 - all your settings are kept too, which is super handy!

chunkysteveo, 2024-12-11:
Typical - 0.15 is now out!

[wled_15.0_YAWL.zip](https://github.com/user-attachments/files/18095510/wled_15.0_YAWL.zip)

iamlite, 2024-12-11:
Awesome, thank you. Works great.

chunkysteveo, 2024-12-11:
> Awesome, thank you. Works great.

Glad to help!!

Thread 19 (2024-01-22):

Programming: purpose of IO line

Andy79881, 2024-01-22:
In terms of programming. How to cope with the IO line? In the figure the line is tied to GND. Could it be a permanent connection or is the line to be tied to Ground at a certain condition or time (e.g. after power-up)?

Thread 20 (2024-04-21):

12V Support

xrtze, 2024-04-21:
The NCP1117LPST33T3G supports up to 18V input... am I right to assume, that the yawl would work fine with 12V like WS2815?

vzagorovskiy, 2024-04-22:
No it won't work.
 You need the signal to be 5V, but it will also be 12V. But there will be no signal because the level converter will burn out. The level converter has a maximum voltage of 5V.
You need to use a DC-DC converter as shown in the figure below.

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

Closed 2024-04-26.

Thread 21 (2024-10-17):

WS2815 Support

Andy79881, 2024-10-17:
Does the YAWL HW-Support 12V LED Stripes as the WS2815?

chunkysteveo, 2025-04-02:
Not in it's current state. Most of the capacitors are rated below 12V, so they would blow if you connected a 12V source to it. The Fuse is only rated to 6V. And the level shifter is only tolerant up to 6.5 V. The voltage regulator would work, so that's good...(!)

So in short - No!

If you replaced the components with similar ones that could tolerate and work with 12V, it would work well.

Orygin, 2025-05-08:
I also am wondering about ws2815 strips.
Would powering the controller with 5v, and the led with 12v work ?
Assuming I connect the grounds of the controller and the strip together

chunkysteveo, 2025-05-09:
> I also am wondering about ws2815 strips. Would powering the controller with 5v, and the led with 12v work ? Assuming I connect the grounds of the controller and the strip together

Actually yes.. if the 12v is isolated to just the LEDs, and you step it down to 5V before inputting to the controller - it _should_ work. The 12V WS2815 still use 5V logic on the data lines. And yeah, both grounds connected.

Orygin, 2025-05-09:
Thanks that's perfect.
I have purchased a strip and power supply to test it, I'll report back if I
experience any issues

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

Orygin, 2025-05-16:
I can confirm I can drive a WS2815 led strip with this controller. Just power the chip with 5v, the LEDs with 12v and bridge the grounds together

chunkysteveo, 2025-05-16:
That's awesome to hear! Good to know the theory works as expected! I have some 12V COB WS2812B chips, so may do this method too.

Thanks!

numindast, 2025-05-16:
This also works fine for 24v strips, as long as you have a source of 5v to feed yawl-controller, that is the key.

I have one at my workbench feeding a 24v FCOB rgbw strip. Neat effects but each "pixel" is a bit chunky. Much better suited to larger space ambient lighting.

chunkysteveo, 2025-05-16:
> This also works fine for 24v strips, as long as you have a source of 5v to feed yawl-controller, that is the key.
>
> I have one at my workbench feeding a 24v FCOB rgbw strip. Neat effects but each "pixel" is a bit chunky. Much better suited to larger space ambient lighting.

Yeah, these 12v ones share about 70mm of COB leds 'per pixel'... smooth gradients don't work too well, but Rainbow blends nicely though 👌🏻

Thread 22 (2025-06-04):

blade fuse doesn't fit 3D printed enclosure

thijsdeschildre, 2025-06-04:
These should be the right fuse and fuse holders, but I can't fit the lid?

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

chunkysteveo, 2025-06-04:
Ahh, almost the right fuses... you can get micro ones which are shorter. These are the ones I got... https://s.click.aliexpress.com/e/_EzcO9Xk

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

You should see that they sit 'within' the fuse holder.

chunkysteveo, 2025-06-04:
Yes - that image shows a red micro fuse, not a mini fuse. A mini fuse will work, but it won't fit in the case that I designed, as you have seen.

thijsdeschildre, 2025-06-05:
thanks for all the quick replies everyone!

> Yes - that image shows a red micro fuse, not a mini fuse. A mini fuse will work, but it won't fit in the case that I designed, as you have seen.

ah, indeed. looks like I bought both the wrong fuses and wrong fuse holders. mini and micro fuse holders all use the same footprint, it seems, so I didn't catch on.

chunkysteveo, 2025-06-05:
Your fuse holders may be OK. Try getting some micro fuses first to see if they fit. My micro fuses are a very tight fit into the holders. Or increase the height of the printer box a little maybe?

Best of luck!

Closed 2025-06-05.

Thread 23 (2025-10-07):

Missing components from JLPCB BOM file

seanbo, 2025-10-07:
I ordered from JLPCB using the Gerber, BOM (JLPCB version), and CPL files provided in the README.  I received a notice from JLPCB that J1, J2, and U4 are missing from the BOM file.  Additionally, I reviewed the other BOM file and see that IR1 and KEY1 are present in that BOM file but not he JLPCB file.  Can you please provide updated and matching BOM/CPL files so I can update my order with JLPCB?

From the Ordering and Manufacturing section
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

Screenshot of email from JLPCB
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

Please let me know if I can provide any further information.  Thank you for your help with this.

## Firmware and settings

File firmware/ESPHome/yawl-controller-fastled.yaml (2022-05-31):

substitutions:
  node_name: yawl-controller
  node_id: yawl_controller
  friendly_node_name: YAWL Controller

esphome:
  name: ${node_name}
  comment: ${friendly_node_name}
  name_add_mac_suffix: true
  project:
    name: lizardsystems.yawl-controller
    version: 1.0.0

esp8266:
  framework:
    version: 2.7.4
  board: esp12e
    

wifi:
  ap: {}


captive_portal:

logger:
  baud_rate: 0
  level: ERROR
  esp8266_store_log_strings_in_flash: false

ota:

web_server:
  port: 80

api:


dashboard_import:
  package_import_url: github://lizardsystems/yawl-controller/edit/main/firmware/ESPHome/yawl-controller-fastled.yaml

binary_sensor:
  - platform: status
    name: ${friendly_node_name} Connection Status
    id: ${node_id}_connection_status
  

  - platform: gpio
    pin:
      number: GPIO0
      mode:
        input: true
        pullup: true
      inverted: true
    name: ${friendly_node_name} Light Button
    id: button_1
    on_press:
        then:
            - light.toggle: light_1
  

text_sensor:
  - platform: template
    name: Uptime Human Readable
    id: uptime_human
    icon: mdi:clock-start

  - platform: version
    name: ${friendly_node_name} ESPHome Version
    id: ${node_id}_esphome_version    

  - platform: wifi_info
    ip_address:
      name: ${friendly_node_name} IP Address
      id: ${node_id}_ip_address
      icon: mdi:ip-network

dallas:
  - pin: GPIO14

sensor:
  - platform: uptime
    name: Uptime Sensor
    id: uptime_sensor
    update_interval: 60s
    on_raw_value:
      then:
        - text_sensor.template.publish:
            id: uptime_human
            state: !lambda |-
              int seconds = round(id(uptime_sensor).raw_state);
              int days = seconds / (24 * 3600);
              seconds = seconds % (24 * 3600);
              int hours = seconds / 3600;
              seconds = seconds % 3600;
              int minutes = seconds /  60;
              seconds = seconds % 60;
              return (
                (days ? to_string(days) + "d " : "") +
                (hours ? to_string(hours) + "h " : "") +
                (minutes ? to_string(minutes) + "m " : "") +
                (to_string(seconds) + "s")
              ).c_str();

  - platform: wifi_signal
    name: ${friendly_node_name} WiFi Signal
    id: ${node_id}_wifi_signal
    update_interval: 60s
    
  - platform: dallas
    index: 0
    name: ${friendly_node_name} Temperature
    

button:
  - platform: restart
    name: ${friendly_node_name} Restart
    id: ${node_id}_restart
    icon: "mdi:restart"
  - platform: shutdown
    name: ${friendly_node_name} Shutdown
    id: ${node_id}_shutdown
  - platform: safe_mode
    name: ${friendly_node_name} Restart (Safe Mode)"
    id: ${node_id}_safe_mode

switch:
  - platform: gpio
    internal: true
    pin: GPIO12
    inverted: true
    name: ${friendly_node_name} Relay
    id: relay_1

remote_receiver:
  pin: GPIO4
  dump: all
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

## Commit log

2021-12-31 Add schematics and gerbers
    [AK-S-80.dwg, AK-S-80.dxf, BOM_PCB_yet another wled controller.csv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]
2021-12-31 Rename schematic files
2022-01-09 Update schematic
2022-01-13 Add ESPHome firmware
    [BOM_PCB_yet_another_wled_controller.csv, BOM_PCB_yet_another_wled_controller_(JLCPCB).xls, yawl-controller.yaml]
2022-01-13 Rename ESPHome firmware folder
    [yawl-controller.yaml]
2022-01-17 Added Fastled firmware Updated ESPHome firmware Light default transition time reduced to 100ms
    [yawl-controller-fastled.yaml, yawl-controller-neopixelbus.yaml]
2022-01-18 Added dashboard_import in ESPHome config
    [yawl-controller-fastled.yaml, yawl-controller-neopixelbus.yaml]
2022-01-22 Updated ESPHome firmware Added script for building ESPHome firmware
    [yawl-controller-fastled.yaml, yawl-controller-neopixelbus.yaml]
2022-02-14 Updated config files, scripts and binaries
    [yawl-controller-fastled.yaml]
2022-03-29 Downgraded Arduino platform to 2.7.4 for Fastled library
    [yawl-controller-fastled.yaml]
2022-05-31 Update yawl-controller-fastled.yaml
    Added package_import_url
    [yawl-controller-fastled.yaml]
2022-12-01 Added 3D printed enclosures
